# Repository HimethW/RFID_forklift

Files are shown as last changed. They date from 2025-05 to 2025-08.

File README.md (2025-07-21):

# 🚜 Forklift-Mounted RFID Reader System

A robust, industrial-grade RFID-based asset tracking system designed for real-time inventory management in warehouse environments. This project integrates embedded hardware and full-stack web technologies to automate and optimize warehouse logistics using a forklift-mounted RFID reader.

---

## 📌 Project Overview

This system enables forklifts to detect RFID-tagged goods during pallet movement and automatically update inventory data via Wi-Fi to a centralized web dashboard. It improves warehouse efficiency by minimizing manual data entry and ensuring accurate, real-time inventory tracking.

---

## 🔧 Key Features

- 📡 **RFID Tag Detection**: High-frequency (13.56 MHz) RFID tag scanning using PN532.
- 🧠 **Embedded Controller**: ATmega328P-based control for RFID and communication tasks.
- 🌐 **Wi-Fi Integration**: ESP8266 transmits data wirelessly to backend server.
- 🖥️ **Web Dashboard**: Real-time inventory tracking and management via React frontend and Express + PostgreSQL backend.
- 🔩 **Custom Enclosure & PCB**: Vibration-resistant, forklift-compatible hardware with modular design and test-point access.

---
## 🧠 System Architecture

```text
[RFID Tag]
    ↓
[PN532 Reader] ←→ [ATmega328P MCU] ←→ [ESP8266 WiFi Module] → [Web Server]
                                                       ↓
                                               [PostgreSQL Database]
                                                       ↓
                                               [React Web Dashboard]

```

## 🎬 Video Demonstration
The video demonstration for our RFID reader can be viewed from [here](https://drive.google.com/drive/folders/12UP2MRnLVZfh7hwHNPXHZd3cqawokBNq?usp=sharing)

## ⚙️ Technologies Used

### 🖥️ Hardware
- ATmega328P (QFP)
- PN532 RFID Reader
- ESP8266-12F Wi-Fi Module
- LM2596 Buck Converter
- Custom PCBs (EasyEDA)
- SolidWorks Enclosure Design

### 💻 Software
- Embedded C (SPI & UART protocols)
- React + Vite (Frontend)
- Express.js (Backend)
- PostgreSQL (Database)
- Node.js

---

## 🚀 Functional Workflow

1. RFID reader (PN532) detects and reads nearby tags.
2. ATmega328P processes the UID and sends it to ESP8266 via UART.
3. ESP8266 transmits tag data to a remote PostgreSQL database.
4. Web app updates inventory and shipment statuses in real time.

---

## 🧪 Field Testing

- Verified tag detection accuracy, Wi-Fi stability, and user workflows  
- Refined enclosure and PCB based on field challenges (vibrations, range, alignment)  

---

## 👨‍💻 Contributors

- Udugamasooriya P.H.J.  
- Perera A.L.C.K.  
- Aazir M.A.M.  
- Ranaweera R.P.D.D.H.
- De Alwis W.M.R. 
- Walgampaya H.K.B.  
- Vidmal S.S.A.A.  
- Rathnayake R.M.T.N.B.  

---

## 📃 License

This project is licensed under the [MIT License](LICENSE).  

---

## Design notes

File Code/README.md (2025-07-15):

## Microcontroller Program for Forklift-Mounted RFID Reader

The microcontroller code consists of the `main.cpp` file containing the main logic running on the device, and five important supplementary libraries, `Pins.h`, `Timer.h`, `SerialInterface.h`, `SPI.h`, and `PN532.h`.

### `Pins` Class

Abstracts away the register level manipulations required to control and communicate with the I/O pins of the ATMega328P. Each I/O pin on the ATMega328P belongs to one of three ports `B` through `D`, and assigned a number `0` through `7`, within that port.

#### Constructor
`Pin pin_name(unsigned char port, unsigned char pin)`

`port` can be any of `B`, `C`, or `D`, and `pin` is any integer from `0` to `7` (both inclusive). Initializes an object to control and communicate with the pin at that port and position.

e.g. `Pin my_pin(B, 7)` refers to pin `PB7` on the ATMega328P.

#### Methods
1. `set_output()`

    Configure the pin as an output pin.

2. `set_input()`

    Configure the pin as an input pin.

3. `assert()`

    Assert the pin, i.e., drive the pin high. Requires the pin to be configured as an output to work.

4. `deassert()`

    Deassert the pin, i.e., drive the pin low. Requires the pin to be configured as an output to work.

5. `toggle()`

    Toggle the pin from its previous state; high to low or low to high. Requires the pin to be configured as an output to work.

6. `state()`

    Read the current logic level at the pin. Requires the pin to be configured as an input to work. Returns `bool`: `true` if the pin is high and `false` otherwise.

7. `is_low()`

    Returns `bool`: `true` if the current logic level at the pin is low, and `false` otherwise. Requires the pin to be configured as an input to work.

8. `is_high()`

    Returns `bool`: `true` if the current logic level at the pin is high, and `false` otherwise. Requires the pin to be configured as an input to work.

### `Timer.h` Library

Uses `TIMER0` on the ATMega328P to generate delays.

#### Functions
1. `initialize_timer()`

    Enable `TIMER0` in the correct mode. Execute once before using any delays.

2. `blocking_delay(unsigned long duration, unsigned char unit)`

    Generate a blocking (program execution halted for the entire duration) delay of `duration` units of time, where `unit` specifies the unit of time. `unit` can be either `MILLISECONDS` or `MICROSECONDS`.

    e.g. `blocking_delay(1000, MILLISECONDS)` generates a blocking delay of 1000 milliseconds or 1 second.

### `SerialInterface` Class

Provides an interface to transmit and receive bytes over the hardware serial port on the ATMega328P. We assume that the CPU clock is 16 MHz.

#### Constructor
`SerialInterface serial_interface_name(unsigned long baud_rate)`

Initializes the hardware serial port to both transmit and receive over the specified `baud_rate`.

#### Methods
1. `send(unsigned char* send_bytes, int num_bytes)`

    Accepts a pointer `send_bytes` to an array of length `num_bytes`, and transmits each byte in the array over the hardware serial transmitter, one after the other, starting with `send_bytes[0]` and ending with `send_bytes[num_bytes - 1]`. Returns `bool`: `true` when all bytes are successfully transmitted.

2. `receive(unsigned char* receive_buffer, int num_bytes)`

    Accepts a pointer `receive_buffer` to an array of length `num_bytes`, and buffers the next `num_bytes` bytes read through the hardware serial receiver into it. The first byte read goes in `receive_buffer[0]` and the last one in `receive_buffer[num_bytes - 1]`. Returns `bool`: `true` when all bytes are successfully received.

### `SPI_Master` Class

Initializes the ATMega328P as an SPI Master and handles data transmission and reception.

#### Constructor
`SPI_Master spi_master_name()`

Define an `SPI_Master` object to access the hardware SPI port on the ATMega328P.

#### Methods
1. `initialize(unsigned char data_order)`

    Initialize the hardware SPI port to send and transmit in the specified `data_order`. `data_order` can be `MSB_FIRST` or `LSB_FIRST`.

2. `send_and_receive_byte(unsigned char send_byte, unsigned char* receive_byte)`

    Send the byte `send_byte` to the slave, and read the byte simultaneously transmitted by the slave into `receive_byte`. Returns `bool`: `true` when the operation is successfully completed.

3. `send(unsigned char* send_bytes, int num_bytes)`

    Accepts a pointer `send_bytes` to an array of length `num_bytes`, and transmits each byte in it over the MOSI pin. Returns `bool`: `true` once all bytes in the array are successfully transmitted.

4. `receive(unsigned char* receive_buffer, int num_bytes)`

    Accepts a pointer `receive_buffer` to an array of length `num_bytes`, and buffers `num_bytes` bytes in it over the MISO pin. Returns `bool`: `true` once `num_bytes` bytes are successfully received.

### `PN532` Class

Provides an interface to communicate with NXP's PN532 RFID chip.

#### Constructor
`PN532 my_pn532(Pin NSS)`

Define a `PN532` object to control the PN532, selected over the `NSS` `Pin`, i.e., `Pin` `NSS` on the ATMega328P must be connected to pin NSS on the PN532.

#### Methods
1. `initialize()`

    Initialize the hardware SPI port for communication with the PN532 and keep it deselected to begin with.

2. `send_bytes(unsigned char* bytes, int length)`

    Send the bytes in the array of length `length` pointed to by `bytes` to the PN532. Returns `bool`: `true` once all bytes are sent.

3. `receive_bytes(unsigned char* buffer, int length)`

    Buffer `length` bytes from the PN532 into the array pointed to by `buffer`. Returns `bool`: `true` when `length` bytes are received.

4. `write_frame(unsigned char* frame, int length)`

    Accept a pointer to an array `frame`, whose entries are the various bytes in a normal information frame, modify it as necessary, and send it to the PN532 over SPI (as defined in the PN532 User Manual).

5. `read_frame(unsigned char* frame_target, int length, bool start = false, bool conclude = false)`

    Buffer `length` bytes of a frame from the PN532 into the array pointed to by `frame_target`. `start` and `conclude` allow to read a frame portion by portion.
    
    If `start` is `true`, an initialization procedure to start reading a frame from the PN532 is performed. If `false`, it is assumed that the initialization was previously performed, and will not be performed; use if a `read_frame` was previously issued, but all bytes of the frame being sent were not read then.
    
    If `conclude` is `true`, a conclusion procedure to conclude reading the frame from the PN532 is performed. Set to `false` if not all of the bytes in the response frame are being buffered, and it is intended to buffer the remaining bytes in the response with future calls to `read_frame`.

    Returns `bool`: `true` if `length` bytes are read.

    e.g. Say the PN532 has a frame of length 20 ready to be read. Three calls to `read_frame` can be made as follows.
    
    `read_frame(buffer_1, 10, true, false)` performs the initialization procedure, and reads the first 10 bytes in the frame into `buffer_1`.
    
    `read_frame(buffer_2, 5, false, false)` reads the next 5 bytes of the frame response into `buffer_2`. The initialization procedure will not be performed.
    
    `read_frame(buffer_3, 5, false, true)` reads the last 5 bytes of the frame into `buffer_3` and performs the conclusion procedure, indicating we have completed reading the frame.

6. `make_normal_information_frame(unsigned char* target_frame, unsigned char TFI, unsigned char* bytes, unsigned char num_bytes)`

    Accept a pointer `bytes` to an array of length `num_bytes` containing the data bytes (`PD0` to `PDn` as per PN532's User Manual) to be included in a normal information frame, the relevant TFI, construct the frame with the frame header and trailer and place it in the array pointed to by `target_frame`.

    `TFI` can be either `TFI_PN532_TO_HOST` or `TFI_HOST_TO_PN532` and indicates the direction of data transfer.

    Two constants `FRAME_HEADER_SIZE` and `FRAME_TRAILER_SIZE` are defined in the library. It is required that `target_frame` have length `FRAME_HEADER_SIZE + num_bytes + FRAME_TRAILER_SIZE`.

7. `ready_to_respond()`

    Returns `bool`. Poll the PN532 for one second see if it has a frame ready to be read in that time. Returns `true` if a frame is detected, and `false` if a timeout occurs before.

8. `check_ack()`

    Returns `bool`. Read a frame from the PN532 and check if it is an `ACK` frame. Returns `true` if it is, and `false` if anything goes wrong.

9. `issue_command(PN532_Command opcode, PN532_Params... params)`

    Construct a normal information frame containing an instruction to the PN532 and send it over SPI. `opcode` must be an `unsigned char`, and possible values are in `PN532_Commands.h`. Follow `opcode` with a comma-separated list of all parameters/arguments required by it. Returns `bool`: `true` if the frame is successfully sent and acknowledged by the PN532.

10. `issue_command_from_array(unsigned char* command_array, int length)`

    Accept an array pointed to by `command_array` of length `length`, whose first entry is the command code (possible values in `PN532_Commands.h`) and following entries are arguments required by the command, and send it to the PN532 over SPI. Returns `bool`: `true` if the frame is successfully sent and acknowledged by the PN532.

11. `receive_command_response(unsigned char* response_buffer, int length, bool start = false, bool conclude = false)`

    See if the PN532 is ready to respond to a command previously issued, and buffer `length` bytes of the response frame into the array pointed to be `response_buffer`. `start` and `conclude` play the same roles as described in `read_frame`. Note that the frame header and trailer will not be stripped, and will also be placed in `response_buffer`; so it must at least have length `FRAME_HEADER_SIZE + 1 + FRAME_TRAILER_SIZE`. Returns `bool`: `true` once `length` bytes of the response are successfully read.

12. `SAMConfig()`

    Configure the PN532 to not use a SAM card. Returns `bool`: `true` if the command executed successfully.

13. `detect_card(unsigned char* card_number, unsigned char* card_data)`

    Scan the field for an ISO-14443 Type A compliant PICC, and if detected, place the logical number assigned to the card by the PN532 in `card_number`, and other details in the array pointed to by `card_data`.
    
    The length of `card_data` will depend on the number of UID bytes of the card and whether or not it is ISO-14443-4 compliant.

    In any case, the first four entries will always be respectively the MSB and LSB of the ATQA response, SAK, and the length of the UID in the number of bytes. The indices of these entries within this array will be `ATQA_MSB_IDX`, `ATQA_LSB_IDX`, `SAK_IDX`, and `UID_LEN_IDX` respectively.

    Hence, the following `card_data[UID_LEN_IDX]` bytes will contain the UID of the card. If the card is ISO-14443-4 compliant, `card[UID_LEN_IDX + card_data[UID_LEN_IDX]]` will contain the length of the `ATS` response, and the following `card[UID_LEN_IDX + card_data[UID_LEN_IDX]]` entries will contain its `ATS` response.

    Returns `bool`: `true` if a card is detected.

14. `get_mifare_classic_card()`

    Scan the field for MIFARE Classic Cards. Returns a pointer to an object of the `MIFARE_Classic_PN532` class if a card is found, containing its `UID`, and a null pointer otherwise.

### `MIFARE_Classic_PN532` Class

Abstracts away a MIFARE Classic Card detected by the PN532 and provides an interface to issue MIFARE Classic commands to the card over the PN532.

#### Constructor
`MIFARE_Classic_PN532 card_name(PN532* pn532_pcd, unsigned char* uid, int uid_length)`

`pn532_pcd` is a pointer to the `PN532` that detected and activated the card (the initiator), and `uid` is a pointer to an array of length `uid_length` `unsigned char`s that holds the UID of the card.

#### Methods
1. `issue_command(MIFARE_Classic_Command mifare_command, MIFARE_Classic_Block block_address, MIFARE_Classic_Data... data)`

    Similar to `PN532.issue_command`; accept and send a MIFARE Classic command to the card, consisting of the command code, an `unsigned char` that goes in `mifare_command` (possible values found in `MIFARE_Classic_Commands.h`), the address of the relevant block in `block_address`, and a comma-separated list of any required parameters/data (all of which must be `unsigned char`s). Returns `bool`: `true` if the command is successfully issued over the PN532.

2. `issue_command_from_array(unsigned char* command_array, int length)`

    Similar to `PN532.issue_command_from_array`. Accept a pointer `command_array` to an array of length `length`, where the first entry is the relevant MIFARE Classic command code, second entry is the address of the relevant block, and remaining entries are any required parameters/data. Returns `bool`: `true` if the command is sucessfully issued over the PN532.

3. `executed_successfully()`

    Check if the command previously issued was executed successfully. Can use in cases where the PN532 does not pass any response received from a MIFARE Classic Card back to the host controller. Returns `bool`: `true` if execution is successful.

4. `receive_command_response(unsigned char* response_buffer, int length)`

    Buffer `length` bytes from the response received from a MIFARE Classic Card to a command previously issued into the array pointed to by `response_buffer`. As per the PN532 User Manual, a response received back from a MIFARE Classic Card will be at most 16 bytes, so `length` is at most 16, and `response_buffer` should be able to hold that many entries. Returns `bool`: `true` if `length` bytes are succesfully buffered.

5. `authenticate_block(unsigned char authentication_type, unsigned char block_address, unsigned char* key)`

    Issue the command to authenticate the block at address `block_address`, using `authentication_type`, which can be either `AUTHENTICATE_KEY_A` or `AUTHENTICATE_KEY_B`, and the authentication key passed in the array pointed to by `key`. Returns `bool`: `true` if the authentication is successful and `false` otherwise.

6. `read_block(unsigned char block_address, unsigned char* contents)`

    Read the contents at the block address specified by `block_address` of a previously authenticate card, into the array pointed to by `contents`. There will be upto 16 bytes in a block, so `contents` should be able to hold upto 16 `unsigned char`s. Returns `bool`: `true` if the block is successfully read.

7. `write_block(unsigned char block_address, unsigned char* contents)`

    Write 16 bytes from the array pointed to by `contents` into the block at the address `block_address` of a previously authenticated MIFARE Classic Card. It is required that `contents` have 16 entries. Returns `bool`: `true` if the writing is successfully completed.

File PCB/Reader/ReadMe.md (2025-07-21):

# PN532 RFID PCB Design

This repository contains the complete PCB design files for an NFC RFID system based on the PN532 chip. The design includes schematic capture, PCB layout, and component libraries.

## Repository Contents

### Design Files
- **Schematic Files**:
  - Antenna circuit
  - Reader chip (PN532) interface
  - Power supply circuitry
  - Hierarchy view (top-level schematic)
  
- **PCB Layout Files**:
  - Complete board layout
  - Layer stackup
  - Manufacturing outputs

### Library Files
- `*.SchLib`: Schematic symbol libraries
- `*.PcbLib`: PCB footprint libraries

### Project Management
- `PN532_final.PrjPcb`: Altium Designer project file (or equivalent for your EDA tool)
- `pn532_LCSC_components.xlsx`: Bill of Materials (BOM) with:
  - All components used
  - Specifications
  - Reference designators
  - Supplier information

## Design Overview

The PCB implements a complete RFID reader solution using NXP's PN532 chip. Key features include:

- Operating frequency: 13.56 MHz
- Communication interfaces: [SPI, UART]
- Power supply: [5V] → [3.3V]
- Antenna design optimized for [Forklift Applications]

## Getting Started

### Prerequisites
- [Altium]

### Opening the Project
1. Clone this repository
2. Open `PN532_final.PrjPcb` in your EDA tool
3. All schematic and layout files should load automatically

## Version History
- v1.0 - Initial release
  - Basic functionality verified
  - Initial PCB prototype tested

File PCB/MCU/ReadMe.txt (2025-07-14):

This file contains the Altium files for the Micro-controller PCB

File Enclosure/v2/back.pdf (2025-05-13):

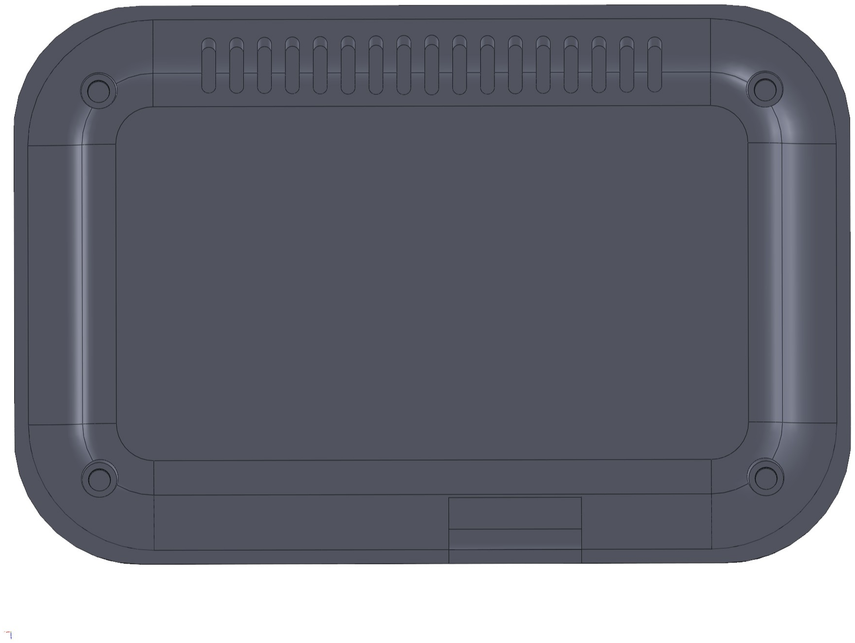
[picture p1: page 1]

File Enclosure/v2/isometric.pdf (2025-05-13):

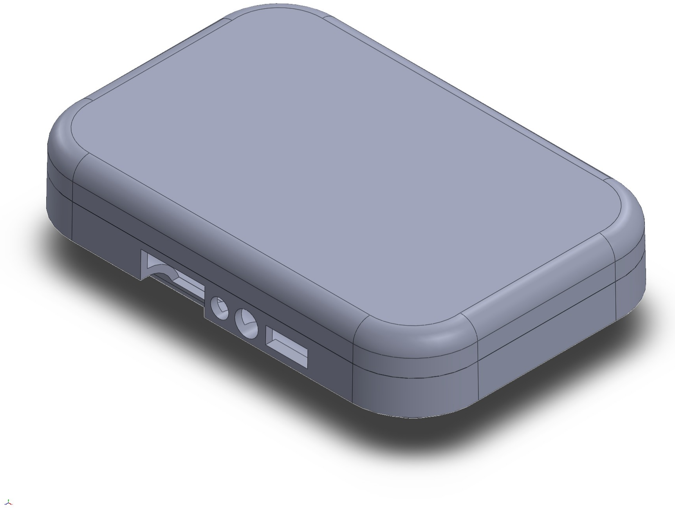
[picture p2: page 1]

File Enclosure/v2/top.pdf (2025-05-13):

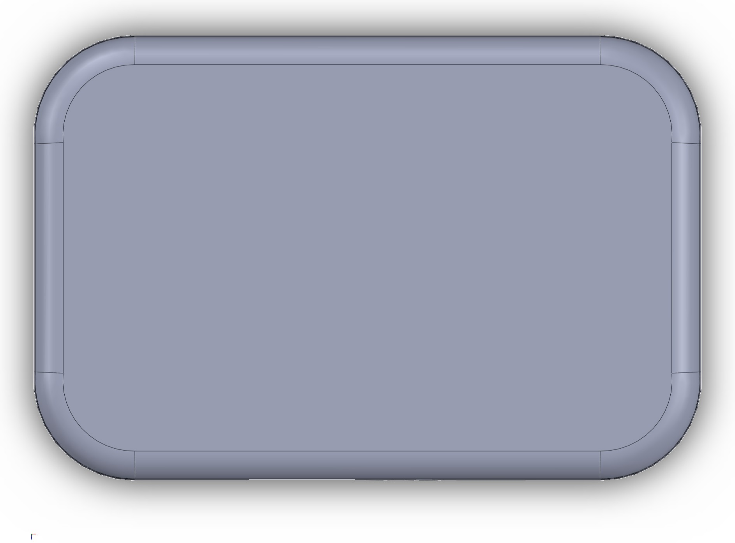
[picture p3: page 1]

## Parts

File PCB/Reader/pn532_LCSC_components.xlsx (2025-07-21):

Component | Components | Manufacture Part | LCSC Part | Manufacturer | Description | Package | Alternative
PN532 | U1 | PN5321A3HN/C106,55 | C28925 | NXP Semicon | QFN-40-EP(6x6) RFID ICs ROHS
220pF | C18,C19 | CC0805FRNPO9BN221 | C541563 | YAGEO | 50V 220pF NP0 ±1% 0805 Multilayer Ceramic Capacitors MLCC - SMD/SMT ROHS | 0805
22pF | C15,C23 | CC0805FRNPO9BN220 | C541515 | YAGEO | 50V 22pF NP0 ±1% 0805 Multilayer Ceramic Capacitors MLCC - SMD/SMT ROHS | 0805
100pF | C16,C20 | CC0805FRNPO9BN101 | C541513 | YAGEO | 50V 100pF NP0 ±1% 0805 Multilayer Ceramic Capacitors MLCC - SMD/SMT ROHS | 0805
1.5Ohm | R5,R8 | AR06FTDV1R50 | C412416 | Viking Tech | 250mW Thin Film Resistor 150V ±50ppm/℃ ±1% 1.5Ω 1206 Chip Resistor - Surface Mount ROHS | 1206
NC resistor | R6,R7 |  |  |  |  | 0402
560nH | L1,L2 | MLJ1608WR56JT000 | C502009 | TDK | 400mA 560nH ±5% 550mA 520mΩ 0603 Inductors (SMD) ROHS | 0603
0.1uF | C1,C2,C6,C7,C8,C10,C13 | CC0805JRX7R8BB104 | C520083 | YAGEO | 25V 100nF X7R ±5% 0805 Multilayer Ceramic Capacitors MLCC - SMD/SMT ROHS | 0805
10uF | C3,C9,C12,C24,C25 | C1206X106J3RACAUTO | C2171358 | KEMET | 25V 10uF X7R ±5% 1206 Multilayer Ceramic Capacitors MLCC - SMD/SMT ROHS | 1206
1kOhm | R4 | TNPW06031K00FEEA | C2131208 | Vishay Intertech | 125mW Thin Film Resistor 75V ±1% ±25ppm/℃ 1kΩ 0603 Chip Resistor - Surface Mount ROHS | 0603 | RT0603FRD071KL
1.69kOhm | R3 | RT1206BRD071K69L | C870510 | YAGEO | 250mW Thin Film Resistor ±25ppm/℃ ±0.1% 1.69kΩ 1206 Chip Resistor - Surface Mount ROHS | 1206 | RC1206FR-071K69L | alt used
1nF | C11 | CC0805FRNPO9BN102 | C326587 | YAGEO | 50V 1nF NP0 ±1% 0805 Multilayer Ceramic Capacitors MLCC - SMD/SMT ROHS | 0805
Ferrite | FB1,FB2 | BLM21AG471SN1D | C397304 | Murata Electronics | 190mΩ ±25% 470Ω@100MHz 0805 Ferrite Beads ROHS | 0805
Oscillator | Y1 | ABM8-27.120MHZ-B4-T | C7209321 | Abracon LLC | 27.12MHz 18pF ±30ppm ±50ppm SMD3225-4P Crystals ROHS | SMD3225-4P
33pF | C4,C5 | GRM1885C1H330GA01D | C426330 | Murata Electronics | 50V 33pF C0G ±2% 0603 Multilayer Ceramic Capacitors MLCC - SMD/SMT ROHS | 0603 | 06035A330FAT2A | alt used
10kOhm | R2 | ERA6VEB1002V | C490804 | PANASONIC | 250mW Thin Film Resistor 150V ±0.1% ±25ppm/℃ 10kΩ 0805 Chip Resistor - Surface Mount ROHS | 0805 | TNPW080510K0BEEA | alt used
LED-power | DS1 | LTST-C150TBKT | C125088 | Lite-On | 20mA 104mcd Colorless Transparent Lens -20℃~+80℃ 465nm~475nm Blue 130° 76mW 3.3V 1206 LED Indication - Discrete ROHS | 1206
10Ohm | R1 | RT0603DRD0710RL | C700510 | YAGEO | 100mW Thin Film Resistor 75V ±0.5% ±25ppm/℃ 10Ω 0603 Chip Resistor - Surface Mount ROHS | 0603
voltage reg | U2 | MIC5225-3.3YM5-TR | C512101 | Microchip Tech | 150mA Fixed 3.3V Positive electrode 16V SOT-23-5 Voltage Regulators - Linear, Low Drop Out (LDO) Regulators ROHS | SOT-23-5
NC capacitor | C14,C17,C21,C22

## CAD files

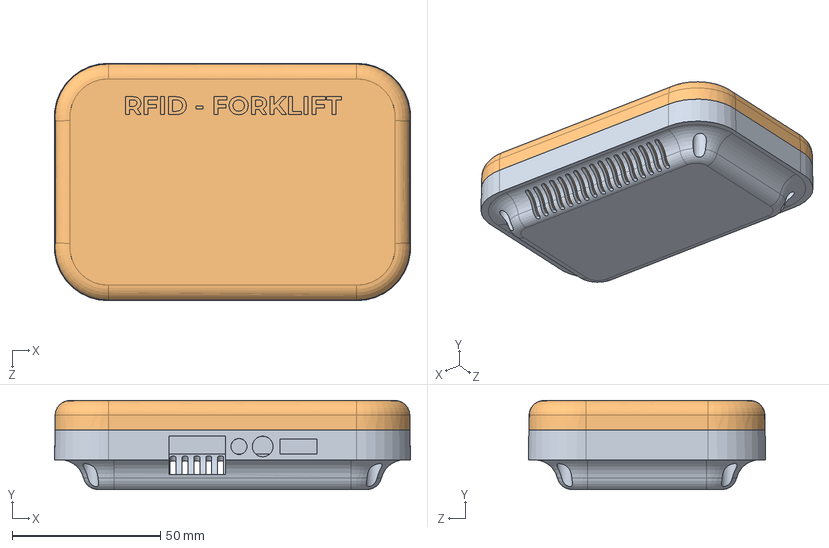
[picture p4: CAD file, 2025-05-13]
Enclosure/v2/full_enclosure.SLDASM
120.0 x 30.0 x 80.0 mm
back_cover
front_cover

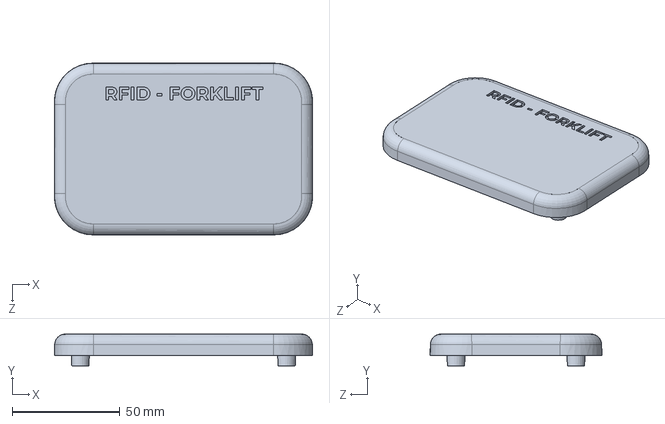
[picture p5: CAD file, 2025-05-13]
Enclosure/v2/front_cover.SLDPRT
119.7 x 14.8 x 79.7 mm

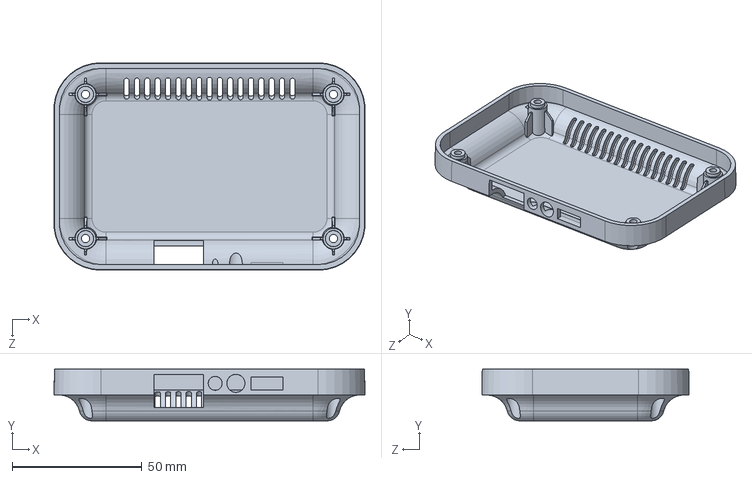
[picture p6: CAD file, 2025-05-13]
Enclosure/v2/back_cover.SLDPRT
120.0 x 20.0 x 80.0 mm

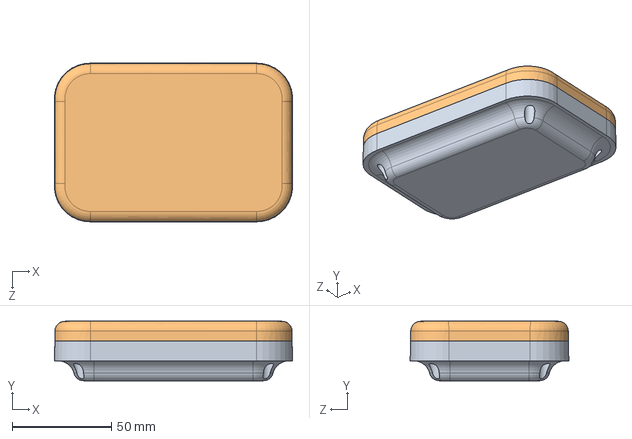
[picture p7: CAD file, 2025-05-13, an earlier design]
Enclosure/v1/Projectassm.SLDASM
120.0 x 30.0 x 80.0 mm
Projectbottom
Projecttop

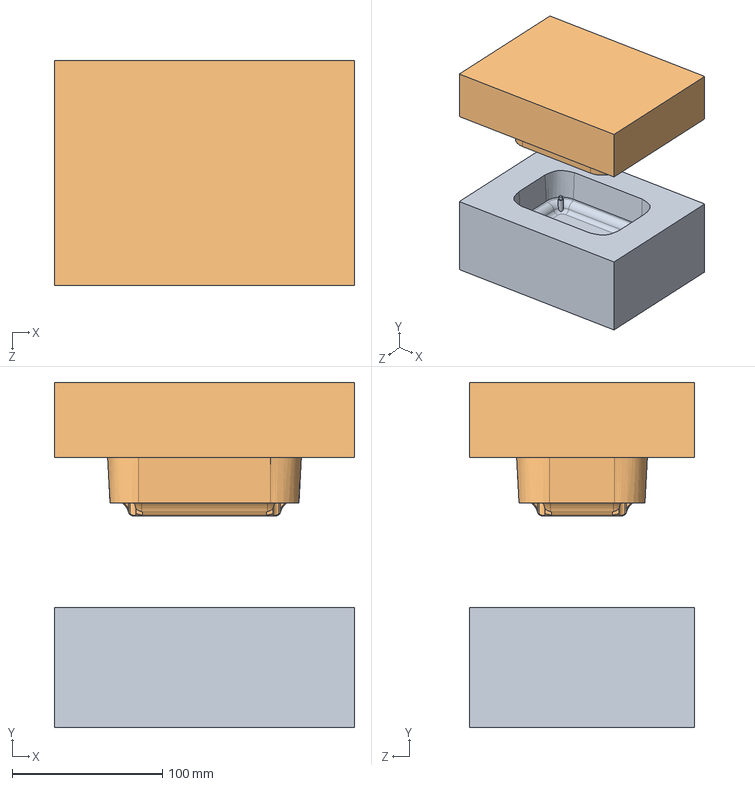
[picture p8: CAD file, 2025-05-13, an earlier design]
Enclosure/v1/Projectbottom_mold_assm.SLDASM
200.0 x 230.0 x 150.0 mm
Projectbottom_mold_cavity
Projectbottom_mold_core

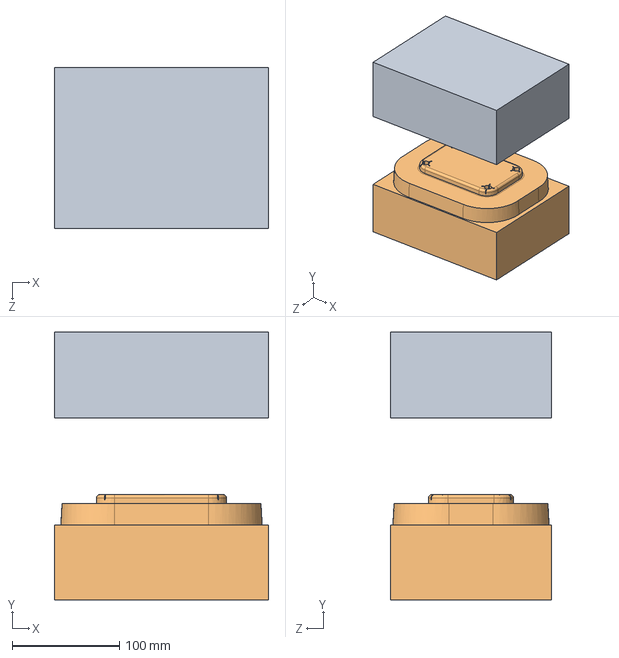
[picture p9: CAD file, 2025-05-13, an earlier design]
Enclosure/v1/Projecttop_mold_assm.SLDASM
200.0 x 250.0 x 150.0 mm
Projecttop_mold_cavity
Projecttop_mold_core

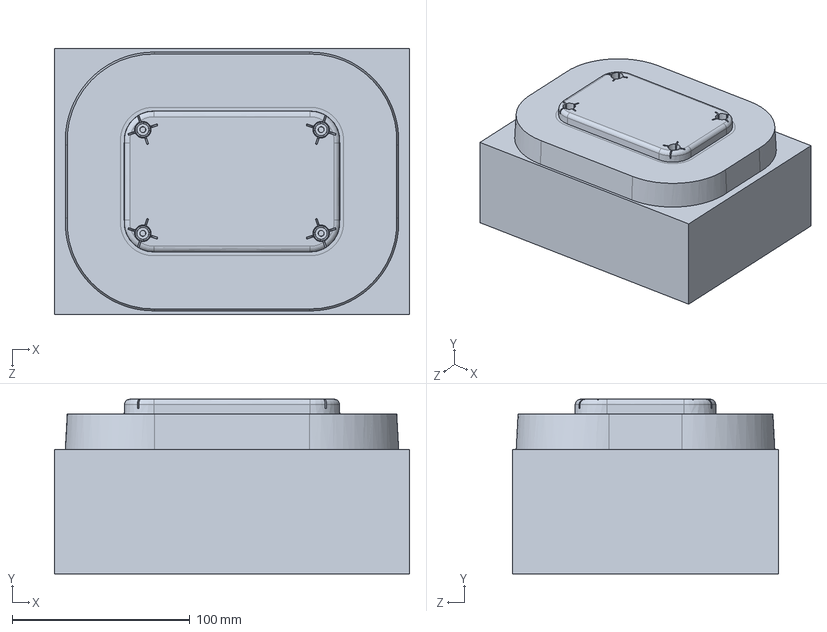
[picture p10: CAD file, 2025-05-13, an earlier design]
Enclosure/v1/Projecttop_mold_core.SLDPRT
200.0 x 98.4 x 150.0 mm

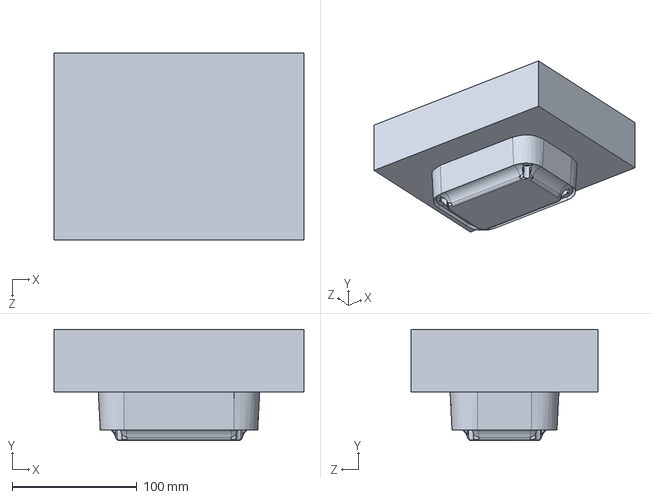
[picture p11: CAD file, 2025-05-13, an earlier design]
Enclosure/v1/Projectbottom_mold_core.SLDPRT
200.0 x 88.9 x 150.0 mm

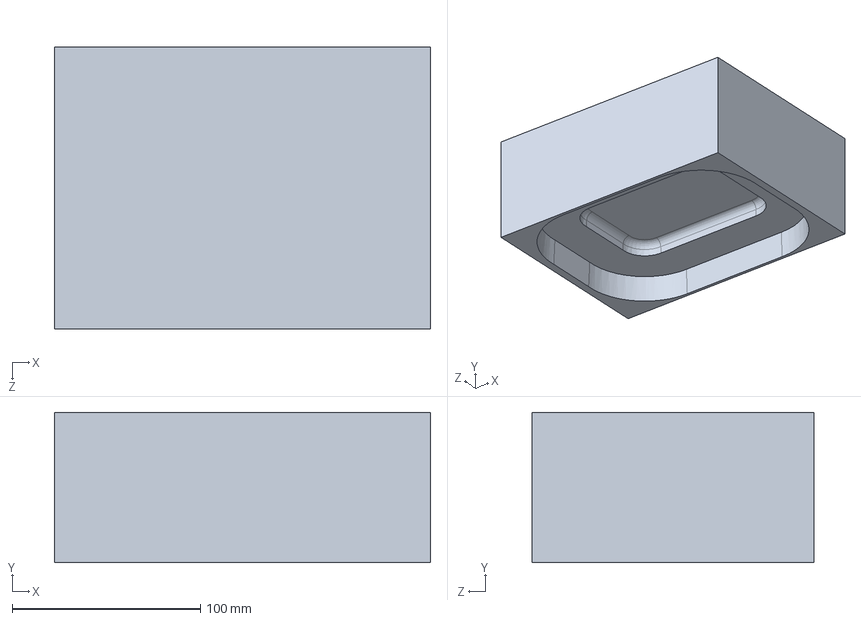
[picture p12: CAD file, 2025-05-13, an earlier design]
Enclosure/v1/Projecttop_mold_cavity.SLDPRT
200.0 x 80.0 x 150.0 mm

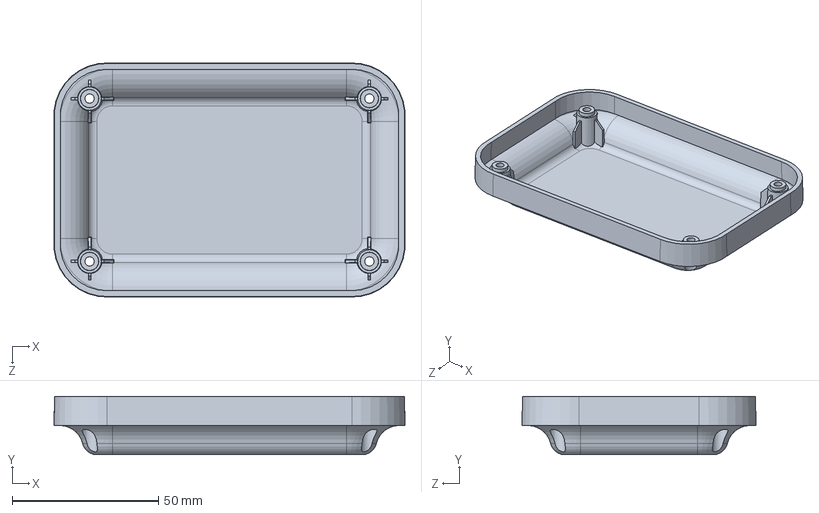
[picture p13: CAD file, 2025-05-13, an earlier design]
Enclosure/v1/Projectbottom.SLDPRT
120.0 x 20.0 x 80.0 mm

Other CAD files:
Enclosure/v1/Projectbottom_mold.SLDPRT
Enclosure/v1/Projecttop_mold.SLDPRT
Enclosure/v1/Projectbottom_mold_cavity.SLDPRT
Enclosure/v1/Projecttop.SLDPRT

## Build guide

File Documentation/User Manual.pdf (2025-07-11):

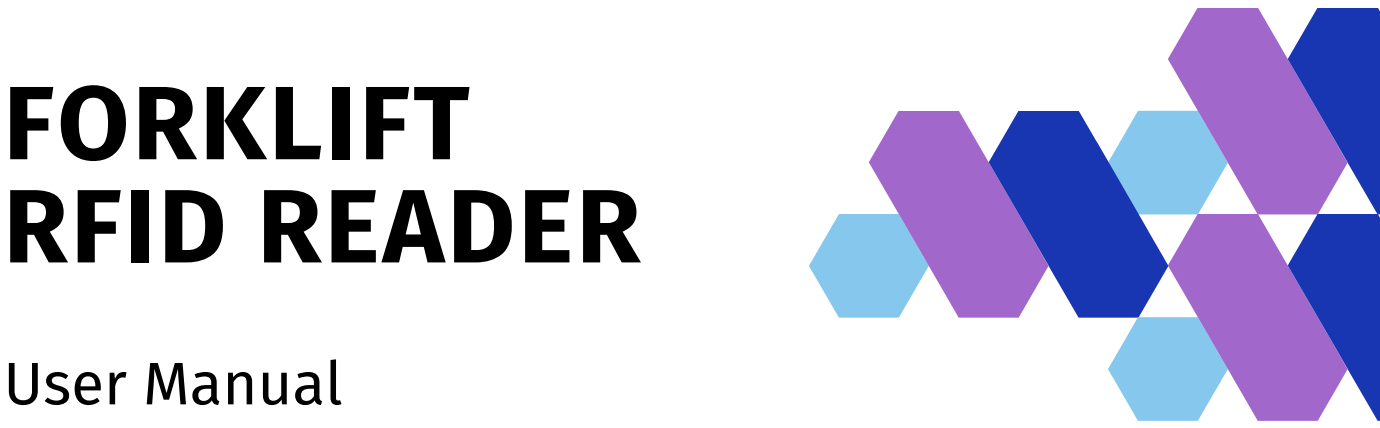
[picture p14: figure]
FORKLIFT RFID READER; User Manual
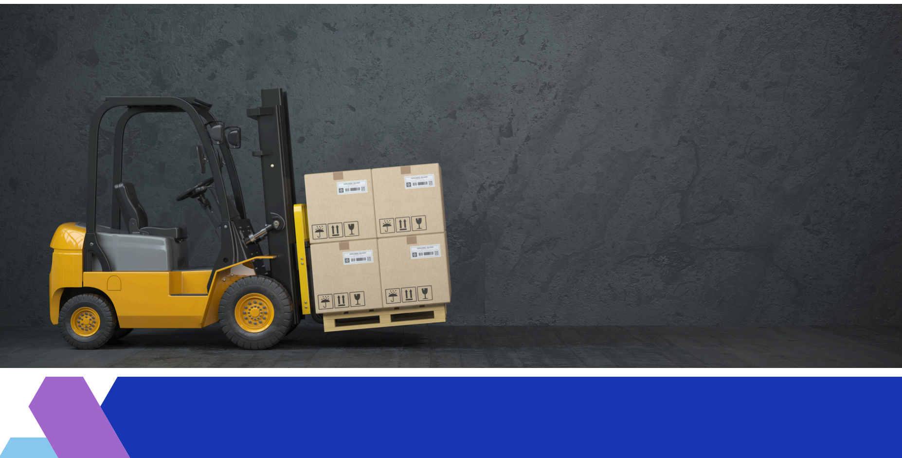
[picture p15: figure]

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
l: H

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
g Introduction Purpose of the Manual Intended Audience Overview of the RFID System Safety Information General Safety Precautions Electrical Safety Mounting Considerations Operating Instructions Powering On the System Reading RFID Tags Data Transmission User Interface Shipments Readers Warehouse Tags Users Maintenance and Troubleshooting Routine Maintenance Common Issues and Solutions

11112333344445555677788101010

## Who Should Read the Getting Started Guide

This section is intended for forklift drivers responsible for moving products within the warehouse. It provides essential information on the proper use, maintenance, and safety procedures related to the RFID reader system installed on the forklift. Understanding and following the guidelines in this manual will help ensure efficient and safe operations, as well as accurate inventory tracking.

# Getting Started Guide

## Overview and Purpose

This is a quick guide that helps forklift operators understand how to start using the RFID reader system installed on their forklifts. By following this guide, users will learn how to power on the device, read RFID tags, and transmit data effectively to the warehouse system.
By the end of this guide, you will:
Know how to start and use the RFID reader on the forklift.
Understand how to interpret tag scans.
Be aware of key maintenance and troubleshooting practices

## Quick Start Tutorial: How to Use the RFID Reader

Step 1: Powering On the System
Ensure the forklift is powered on.
Ensure the power cable is connected to the vehicle battery
The RFID reader will automatically boot up with the vehicle.
Check the indicator lights on the reader to confirm power and readiness.
Step 2: Reading RFID Tags
Drive the forklift to the newly arrived shipment
Move the forklift to a specific product where the tag is in a readable range. (The maximum readable range is 10cm)
The buzzer indicates the detection of the tag
Move the product to the destination pallet
Drive the forklift to a distance where it can detect the tag on the pallet
After detecting the pallet, you can successfully load the product on to the pallet

All the data handling tasks throughout the above process is automated. All the details regarding the interaction with the website is explained in the following sections.

## Maintenance and Troubleshooting

Regular Maintenance:
Wipe down RFID reader daily.
Check all cable connections weekly for wear or loosening.
Report any unusual noises or lights to the maintenance team.
Common Issues & Solutions:
Reader not powering on: Check forklift battery and power cable connections. No tag reads: Ensure tag is within range and not damaged. Restart reader. Data not syncing: Confirm forklift is in a network coverage area.

Always be cautious not to damage the reader while loading products onto the forklift.

This manual provides comprehensive guidance on the operation, and maintenance of the forklift-mounted RFID reader system. It is designed to assist users in effectively utilizing the RFID technology to enhance warehouse operations, ensuring accurate tracking of goods, improved inventory management, and streamlined logistics processes.

## Purpose of the Manual

# Introduction

## Intended Audience

This manual is intended for the following personnel:
Forklift Operators: Individuals responsible for the day-to-day operation of forklifts equipped with RFID readers.
System Administrators: Staff overseeing the integration of the RFID system with warehouse management systems and ensuring data integrity.
Each section of this manual is tailored to provide relevant information to these user groups, facilitating safe and efficient use of the RFID reader system.

## Overview of the RFID System

The forklift RFID reader system is an advanced solution designed to automate the identification and tracking of goods within a warehouse environment. By integrating RFID technology directly onto forklifts, the system enables real-time data capture as items are moved, loaded, or unloaded, thereby enhancing operational efficiency and accuracy.

Key components of the system include:
RFID Reader Unit: Mounted on the forklift, it emits radio signals to detect RFID tags on goods. Display on Mobile App: Provides real-time feedback to the operator, displaying information such as tag reads and system status.
Power Supply Integration: Connects to the forklift's power system, ensuring continuous operation without the need for separate charging.
Data Communication Interface: Facilitates the transfer of collected data to the warehouse management system for processing and record-keeping.
By employing this system, warehouses can achieve improved inventory accuracy, reduced manual scanning errors, and enhanced visibility into the movement of goods.

Ensuring safety during the operation and maintenance of the forklift RFID reader system is paramount. Adhere to the following precautions to prevent accidents and equipment damage: Training: Only trained and authorized personnel should operate forklifts equipped with RFID readers.
Awareness: Be mindful of the RFID reader placements to avoid collisions with warehouse structures or other equipment.
Load Handling: Exercise caution when lifting or lowering loads to prevent contact with RFID reader and to avoid damaging it during the process
Maintenance: Regularly inspect the RFID system for signs of wear or damage. Report any issues to the maintenance team promptly.

## General Safety Precautions

# Safety Information

The RFID reader system involves electrical components that require careful handling:
Power Connection: Consult with the forklift maintenance provider before connecting the RFID system to the vehicle's power supply. Use a multi-conductor cable for power connections, ensuring compatibility with the forklift's electrical system.
Battery Drain: Avoid connecting the RFID reader directly to the forklift battery without a means to control power flow. Continuous power draw can deplete the battery, potentially immobilizing the forklift. Implement a dedicated switch or integrate the system with the ignition switch to manage power effectively.
Voltage Spikes: Use a DC/DC power supply kit to filter voltage spikes that may occur during forklift startup, protecting the RFID reader's internal components.

## Electrical Safety

Proper installation of the RFID reader is crucial for safe and efficient operation: Placement: Mount the RFID reader and antennas in locations that do not obstruct the operator's view or interfere with forklift operations.
Secure Installation: Use appropriate mounting hardware to firmly attach components, preventing movement or detachment during operation.
Cable Management: Route cables through protective conduits and secure them to avoid entanglement or damage from moving parts.

## Mounting Considerations

To ensure the RFID reader system operates correctly, follow these steps to power it on:
1.Verify Power Connections: Ensure that the RFID reader is securely connected to the forklift's power supply through the multi-conductor cable integrated with the forklift's electrical system. 2.Ignition Activation: Turn the forklift's ignition key to the "ON" position. The RFID reader is designed to power on automatically with this ignition, ensuring synchronized operation. 3.System Initialization: Observe the RFID reader's status indicators:
Power LED: Should illuminate steadily, indicating that the reader is receiving power. 4.Navigate to the RFID reader App on the driver’s smartphone.

## Powering On the System

# Operating Instructions

The RFID reader is designed to automatically detect and read RFID tags within its operational range. To effectively read tags:
1.Approach the Load: Drive the forklift towards the pallet or item equipped with RFID tags. Ensure that the tags are within 10cm range from the reader.
2.Optimal Positioning: Align the forklift so that the RFID tags are directly in front of the reader. Proper alignment ensures accurate and efficient reading.
3.Reading Process: Pause briefly to allow the reader to scan the tags. The mobile App indicates the successful detection of the RFID tag as well the buzzer inside the reader.
4.Data Verification: Check the mobile App to confirm that the correct tag information has been captured.
5.Proceed with Operation: Once tag data is verified, continue with the intended task, transporting the load to its designated location.
Note: Ensure that tags are not obstructed by metal objects or other materials that may interfere with radio frequency signals.

## Reading RFID Tags

## Data Transmission

After reading RFID tags, the system transmits the collected data to the warehouse management system (WMS) for processing and record-keeping. The transmission process involves:
Wireless Communication: The RFID reader communicates with the WMS via the warehouse's wireless local area network (WLAN), ensuring real-time data transfer.
Data Formatting: Captured tag information is formatted to ensure compatibility with the WMS. Acknowledgment: The system confirms successful data transmission, which can be viewed on the mobile App status of the readers and tags (explained in the User Interface section).
Note: Ensure that the forklift remains within the coverage area of the WLAN to maintain

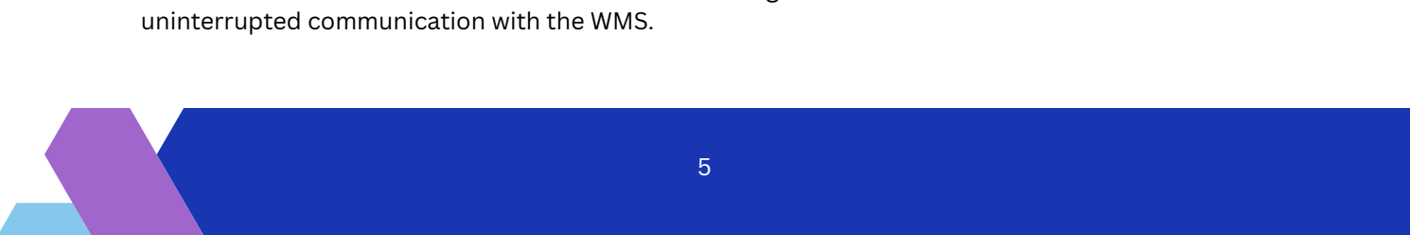
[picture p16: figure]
uninterrupted communication with the WMS.

## User Interface

Tracking of the movements of the products is entirely automated. The status of the process at a particular moment can be understood through the client application in the mobile App and the warehouse management system. The client application in the mobile App and the warehouse management system has similar display and functionality.

You have to log in to the client application by entering your username and password. The system identifies whether you are a warehouse administrator or an RFID reader user and redirects you to the appropriate web page.

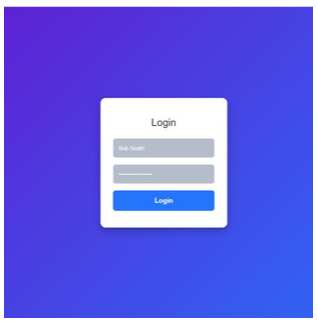
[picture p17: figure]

The web page redirected for RFID reader users is shown on the left. The user can view all the tags scanned so far with the tag name, scanned date, and time. You can also manually add RFID tags through the option at the top of the web page.

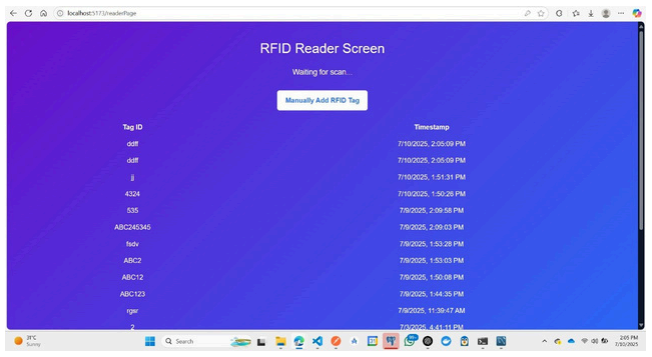
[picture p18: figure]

If you are a warehouse
administrator, you will be redirected to the webpage
shown on the right.
Initially, you will be in the Shipments tab, one of the
five main tabs: Shipments, Readers, Warehouse, Tags,
and Users.

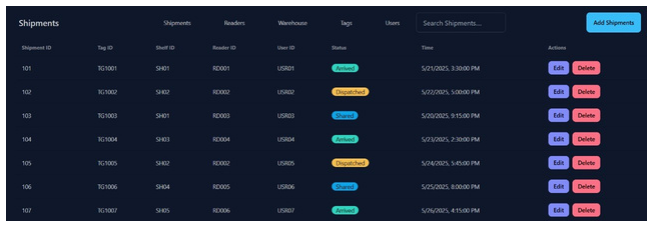
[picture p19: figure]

Shipments
This tab contains all the
information about a particular product in the warehouse. The id of the shipment which the product arrived, id of the tag assigned to it, id of the shelf if it’s successfully loaded on to the corresponding pallet in the

When a new shipment arrives at the warehouse, the management should add the tag information to the warehouse through the Add Shipments option on the top right
The status of the product at this moment is displayed as arrived. Once a forklift reads that tag it changes the status into dispatched, and the forklift moves it to the intended pallet. When the forklift reads the id of the specific pallet the tag status changes to shelved and the forklift loads it to that pallet.

warehouse, id of the reader if its currently on the move on that corresponding reader, id of the user which is the forklift if its currently on the move on it, status which can be either indicating as arrived, dispatched or shelved.

Readers
The reader can be forklift or handheld RFID which is indicated under the type. Each reader is given a specific id and a name. When a forklift reads a tag from a shipment its status is indicated as working. When it reads the id of a specific pallet before unloading the product on it, its status change into idle.

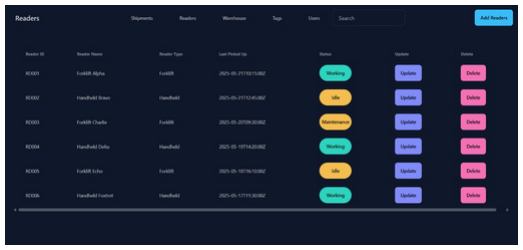
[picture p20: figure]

the warehouse management can add new readers through the Add Reader option on the top right.

Warehouse
Details of the warehouses in the complex can be found here. Each warehouse is given a specific id and a name. It also displays the information of the shelves located in it which includes the id of a particular shelf and the location of it in the warehouse.

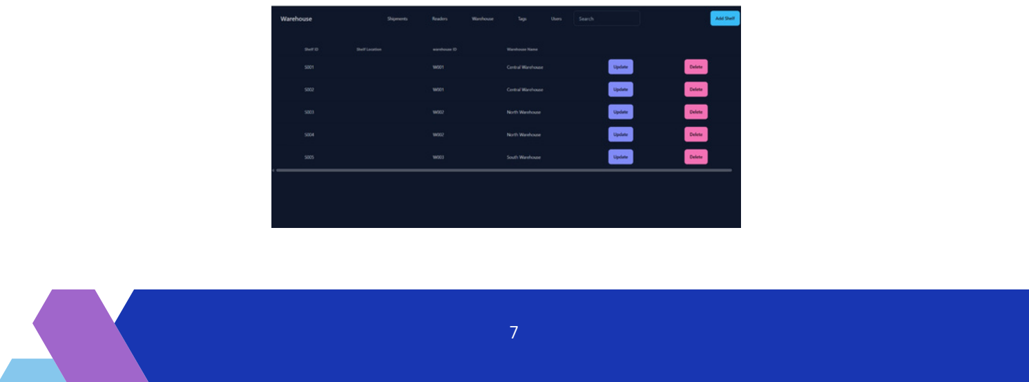
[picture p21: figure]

The warehouse management can add new warehouses through the Add Warehouse option on the top right.

Tags

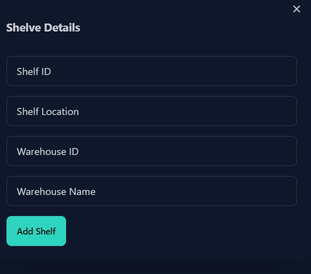
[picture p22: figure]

This tab contains all the information of the products that has been entered to the warehouse data base. It specifies the tag id along with type of the product that id.

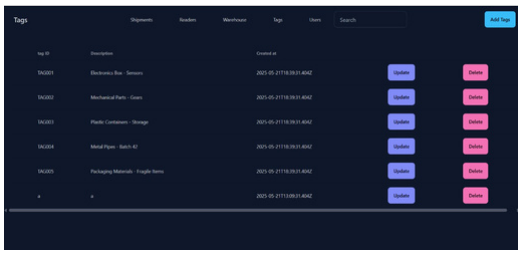
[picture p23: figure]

The warehouse management can add new tags through the Add Tag option on the top right.

Users
Details of the users of the RFID readers are included in this tab. They can be either forklifts or handheld RFIDs.

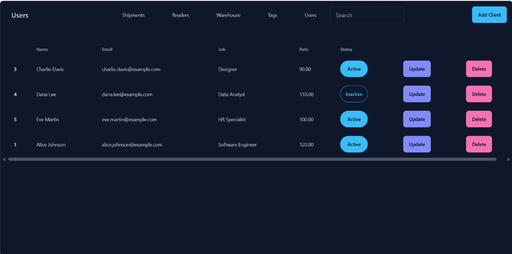
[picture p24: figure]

The warehouse management can add new users through the Add User option on the top right.

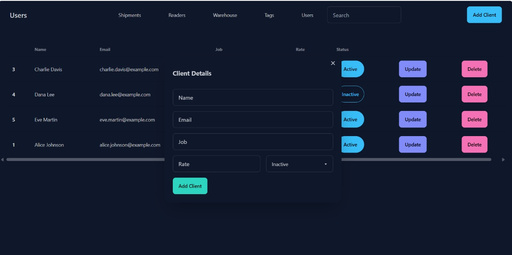
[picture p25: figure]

You can search a specific entry in each of the tabs through the search option on the top right

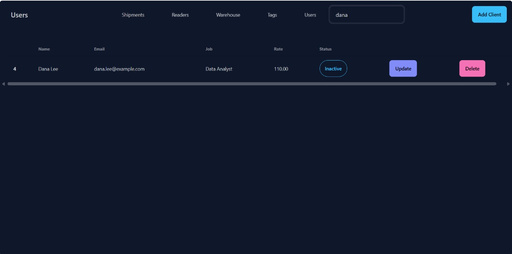
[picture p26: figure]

You can delete any entry from the data base on any tab through the delete option

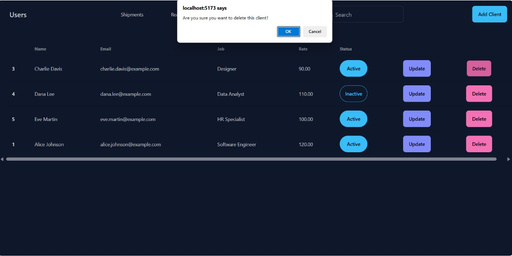
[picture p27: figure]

# Maintenance and Troubleshooting

## Routine Maintenance

Regular maintenance ensures the longevity and optimal performance of the forklift RFID system. Implement the following practices:
Visual Inspections: Periodically check RFID readers, antennas, and cables for signs of wear, damage, or loose connections.
Cleaning: Gently clean RFID components using anti-static materials to remove dust and debris that may interfere with operation.
Software Updates: Regularly update the firmware and software of RFID devices to ensure compatibility and incorporate performance enhancements.
Environmental Monitoring: Ensure that RFID components are operating within the suitable environmental conditions, avoiding exposure to extreme temperatures, moisture, or corrosive substances.
Cable Management: Secure and organize cables to prevent entanglement or damage from moving parts. Utilize cable trays or conduits where appropriate.
Issue | Possible Cause | Recommended Solution
Reader not powering on | Loose or disconnected power cable | Verify and secure all power connections
Reader not powering on | Faulty power supply | Test and replace the power supply if necessary
Inconsistent tag reads | Antenna misalignment | Adjust antenna positioning for optimal tag detection

## Common Issues and Solutions

The following table outlines potential issues with the RFID system and recommended solutions:

Inconsistent tag reads | Interference from metal objects | Reposition tags or use on-metal RFID tags to mitigate interference
No data transmission to WMS | Network connectivity issues | Check network connections and configurations
System freezes or becomes unresponsive | Software glitches or memory overload | Restart the system and monitor for recurring issues; update software to the latest version
Reader does not pick up the tag | Faulty antenna | Test with a known good antenna to determine if replacement is necessary

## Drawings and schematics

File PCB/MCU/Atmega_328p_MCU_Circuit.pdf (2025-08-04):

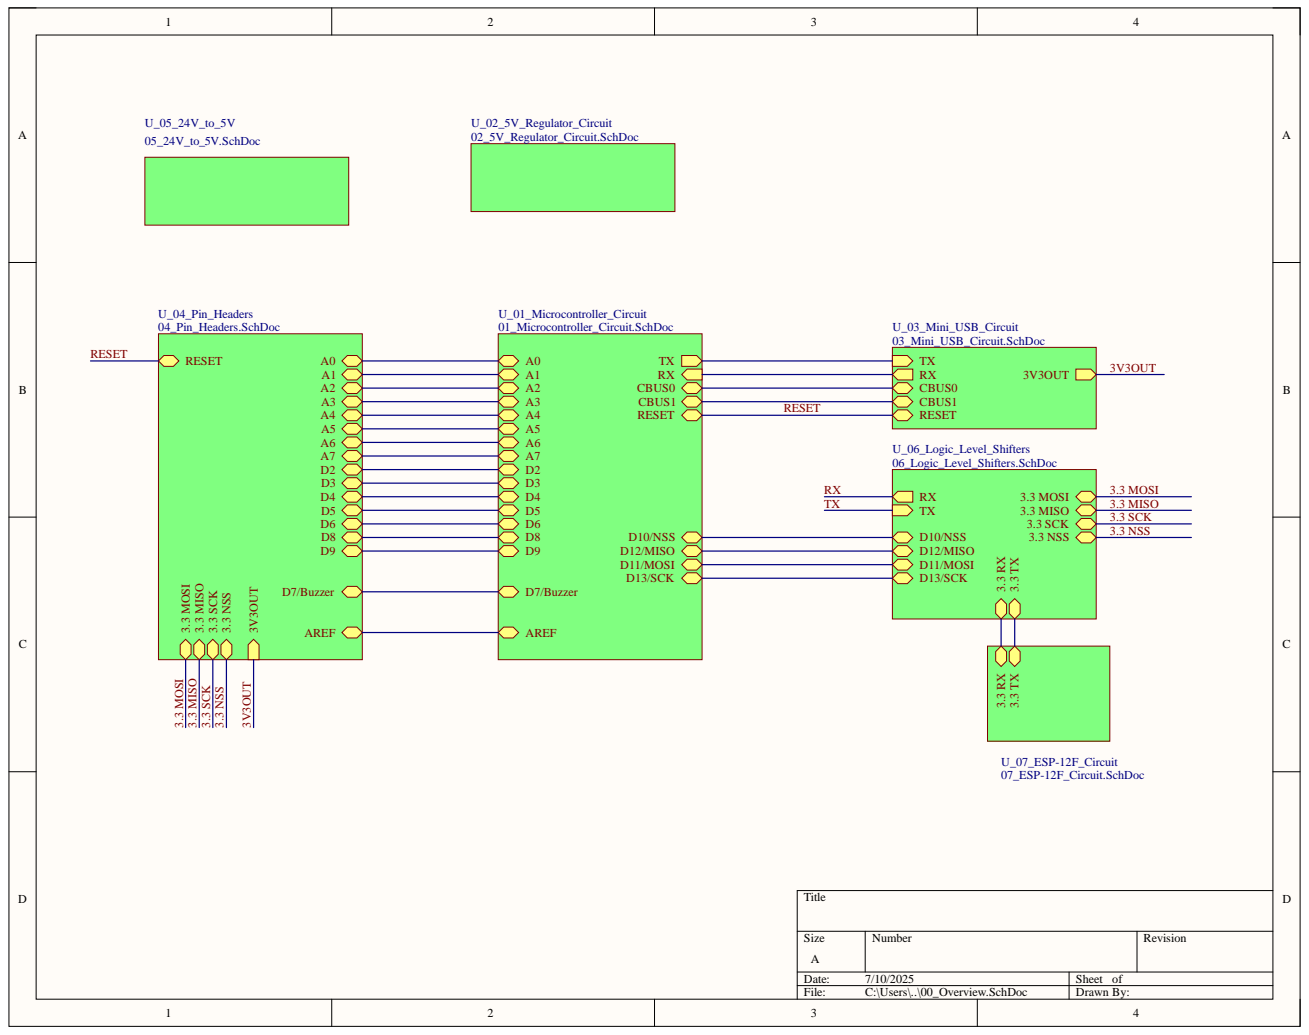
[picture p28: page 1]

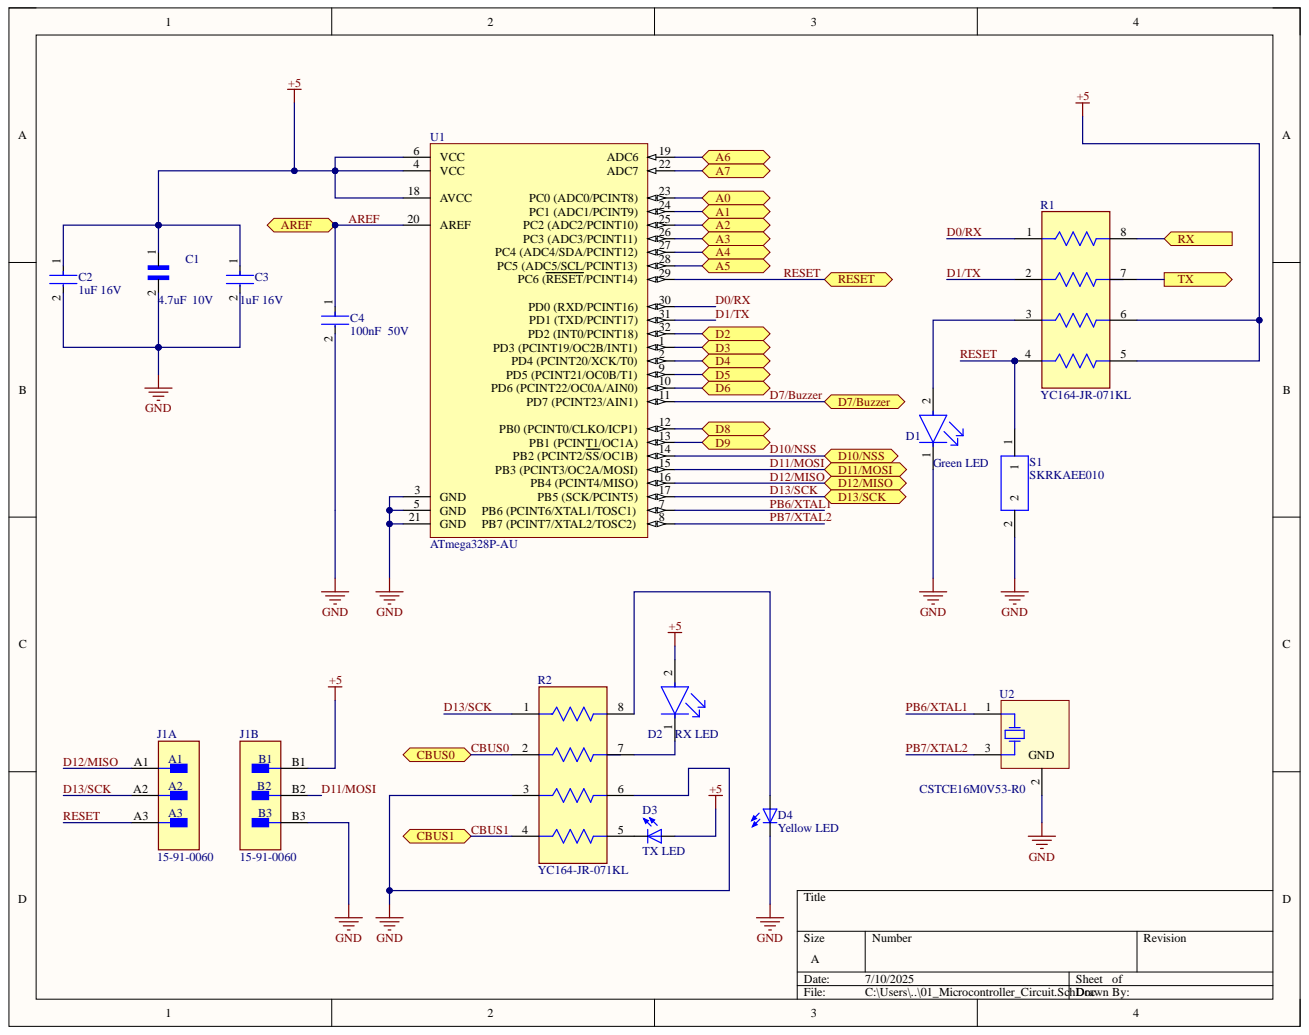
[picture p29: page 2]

AVCC 18

C1 | | GND 3

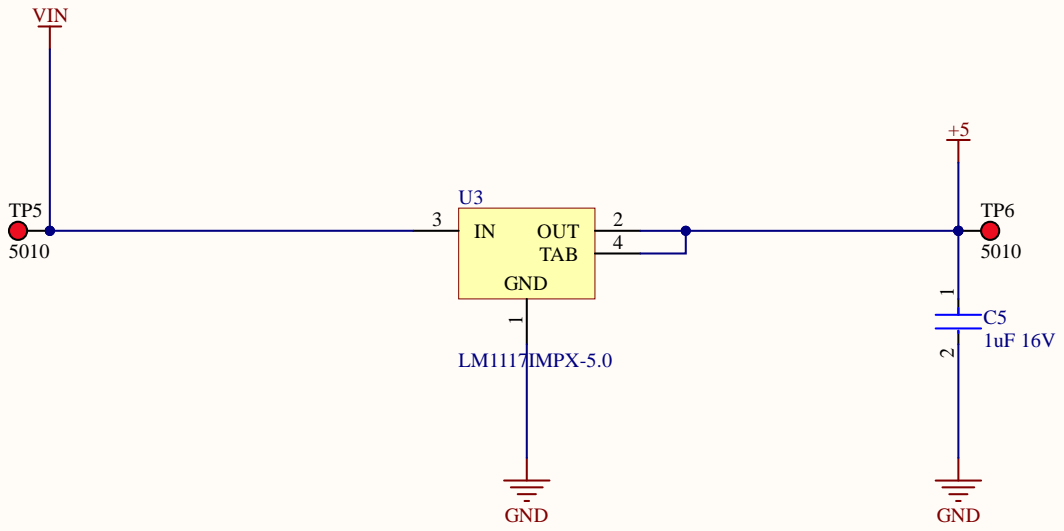
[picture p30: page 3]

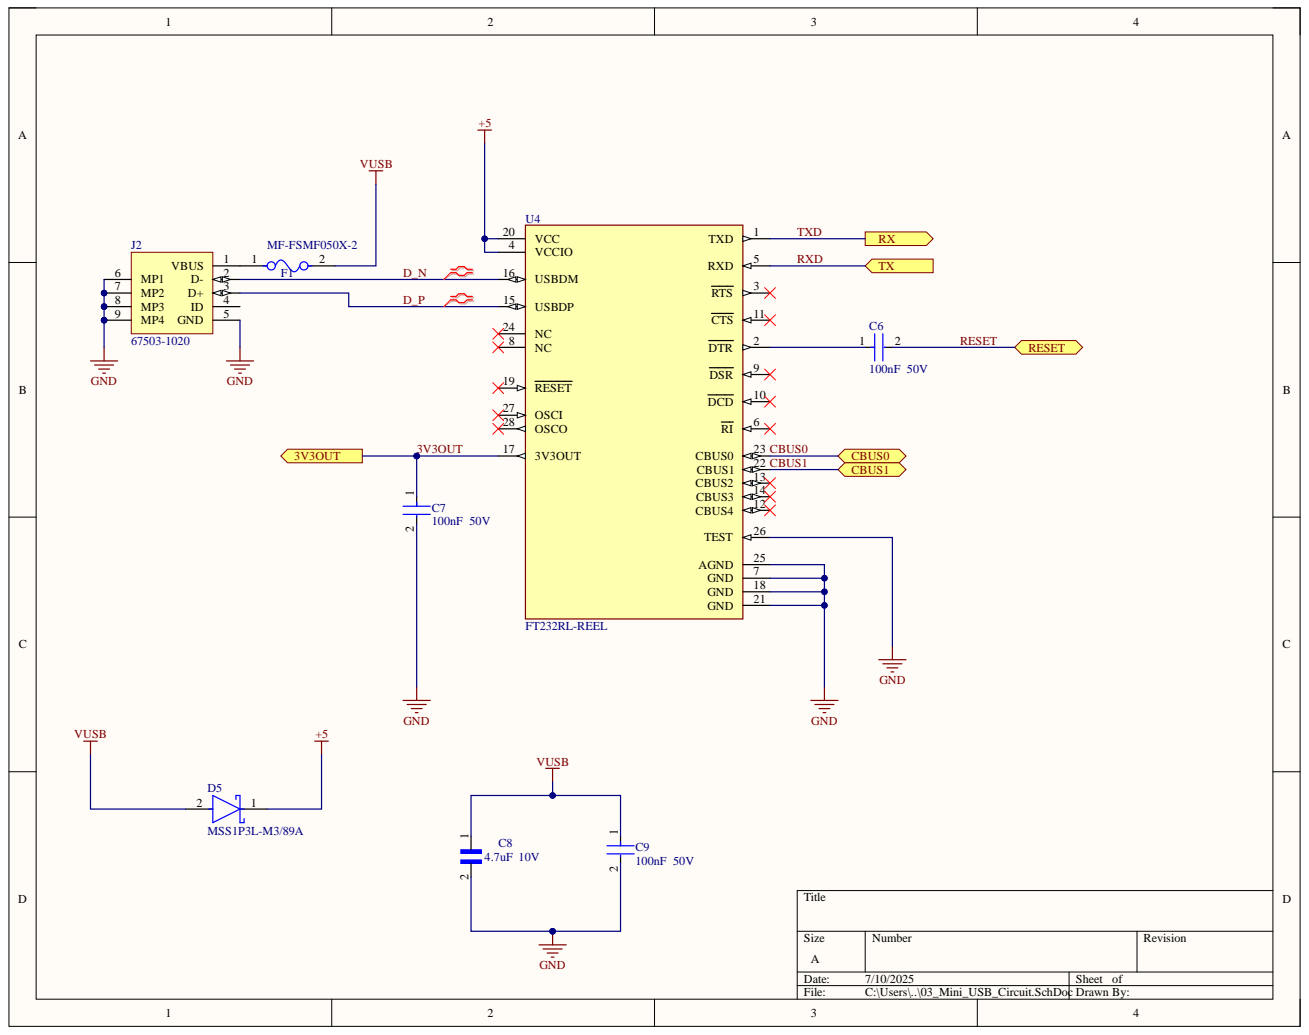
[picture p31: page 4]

MP3 8 | D_P
MP4 9 | NC 8 NC 24

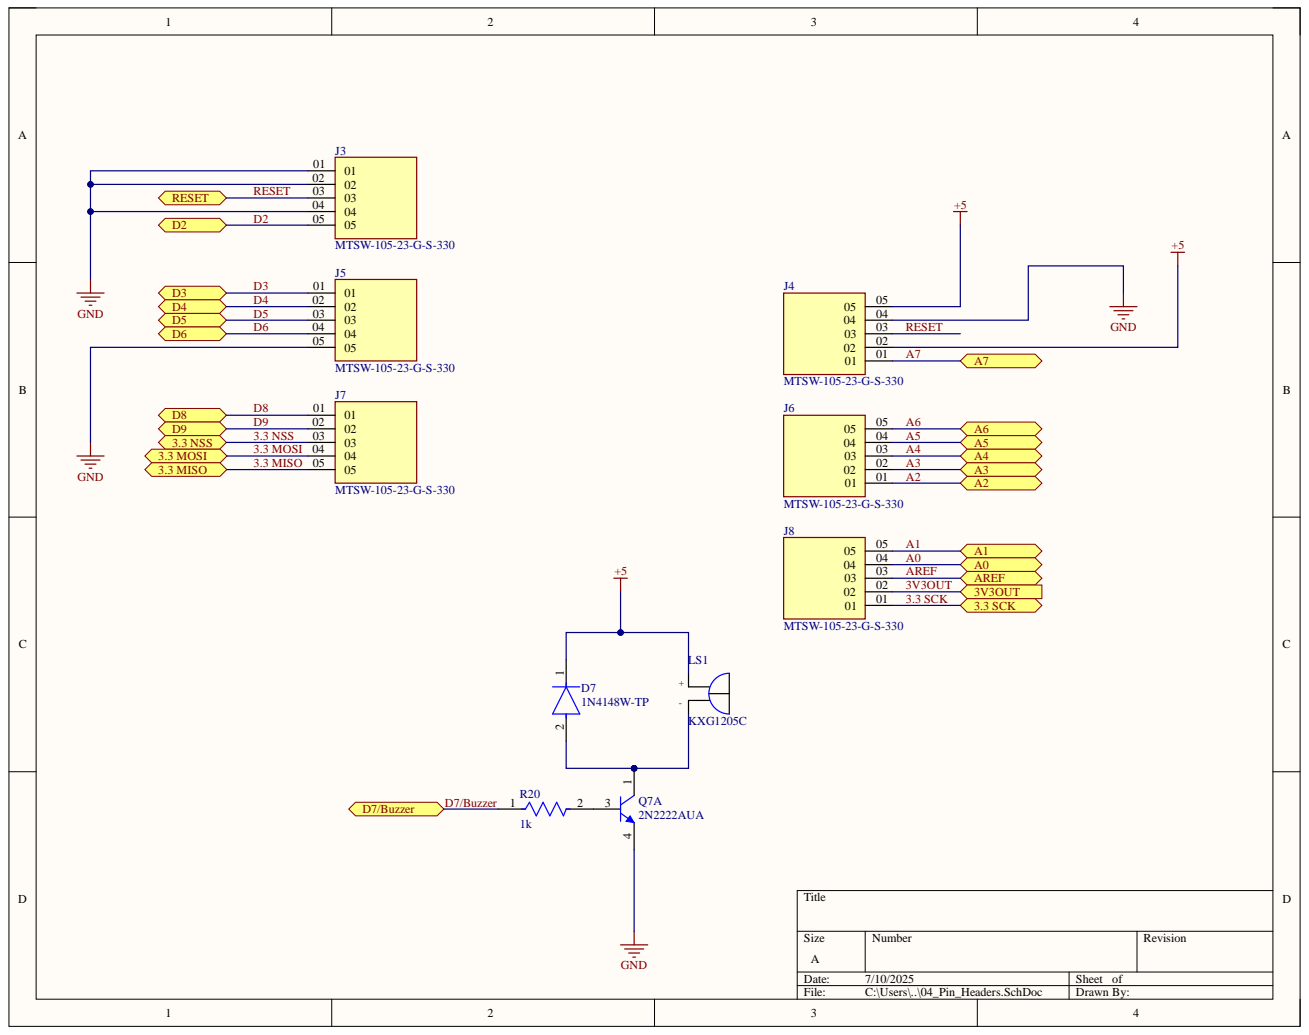
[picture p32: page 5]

RESET | 03 03 04 04

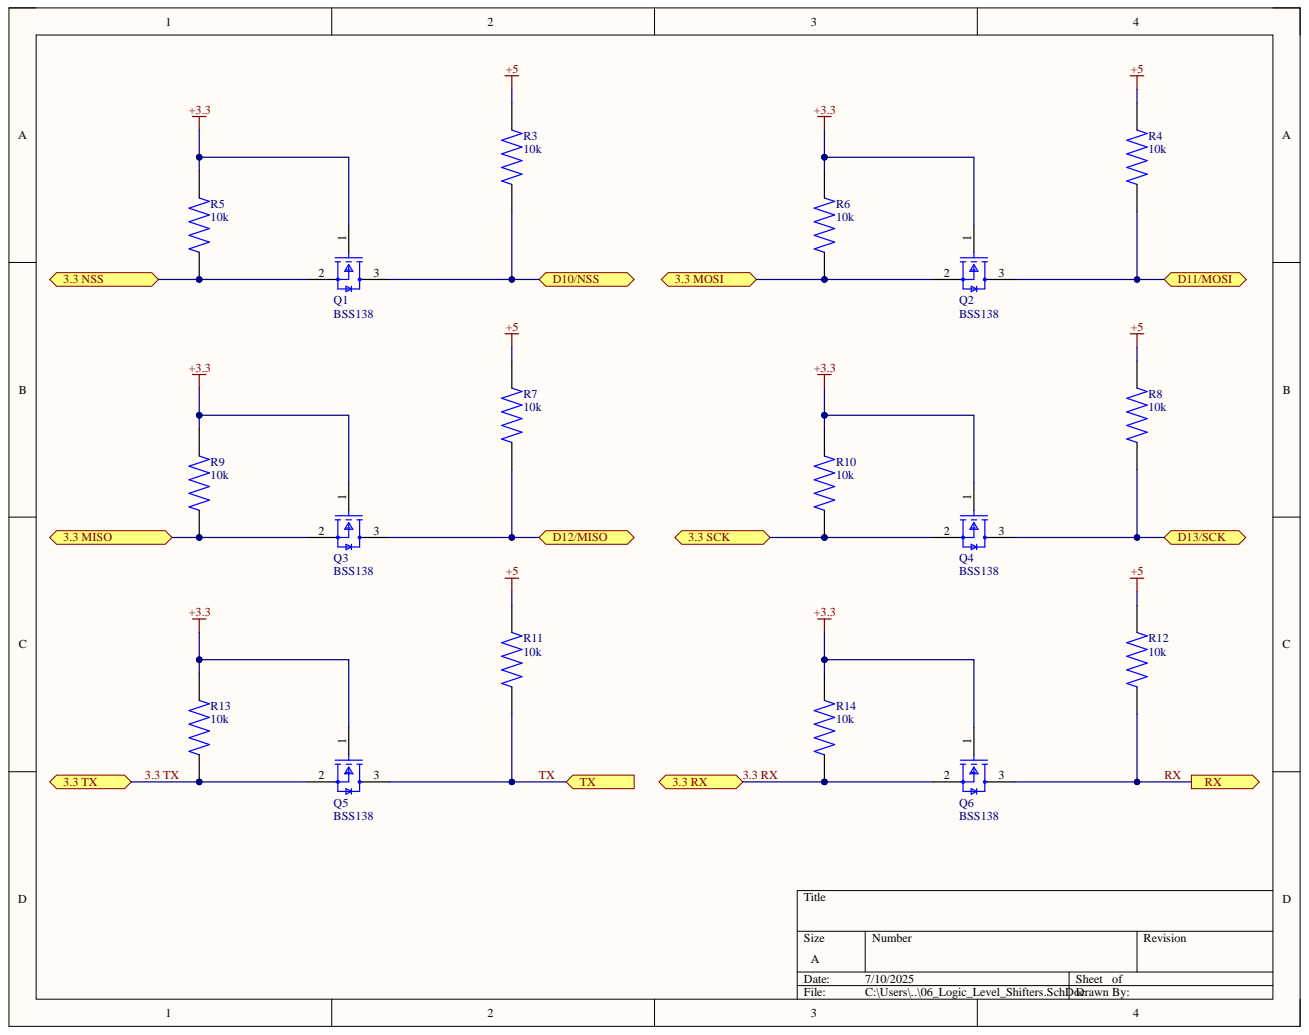
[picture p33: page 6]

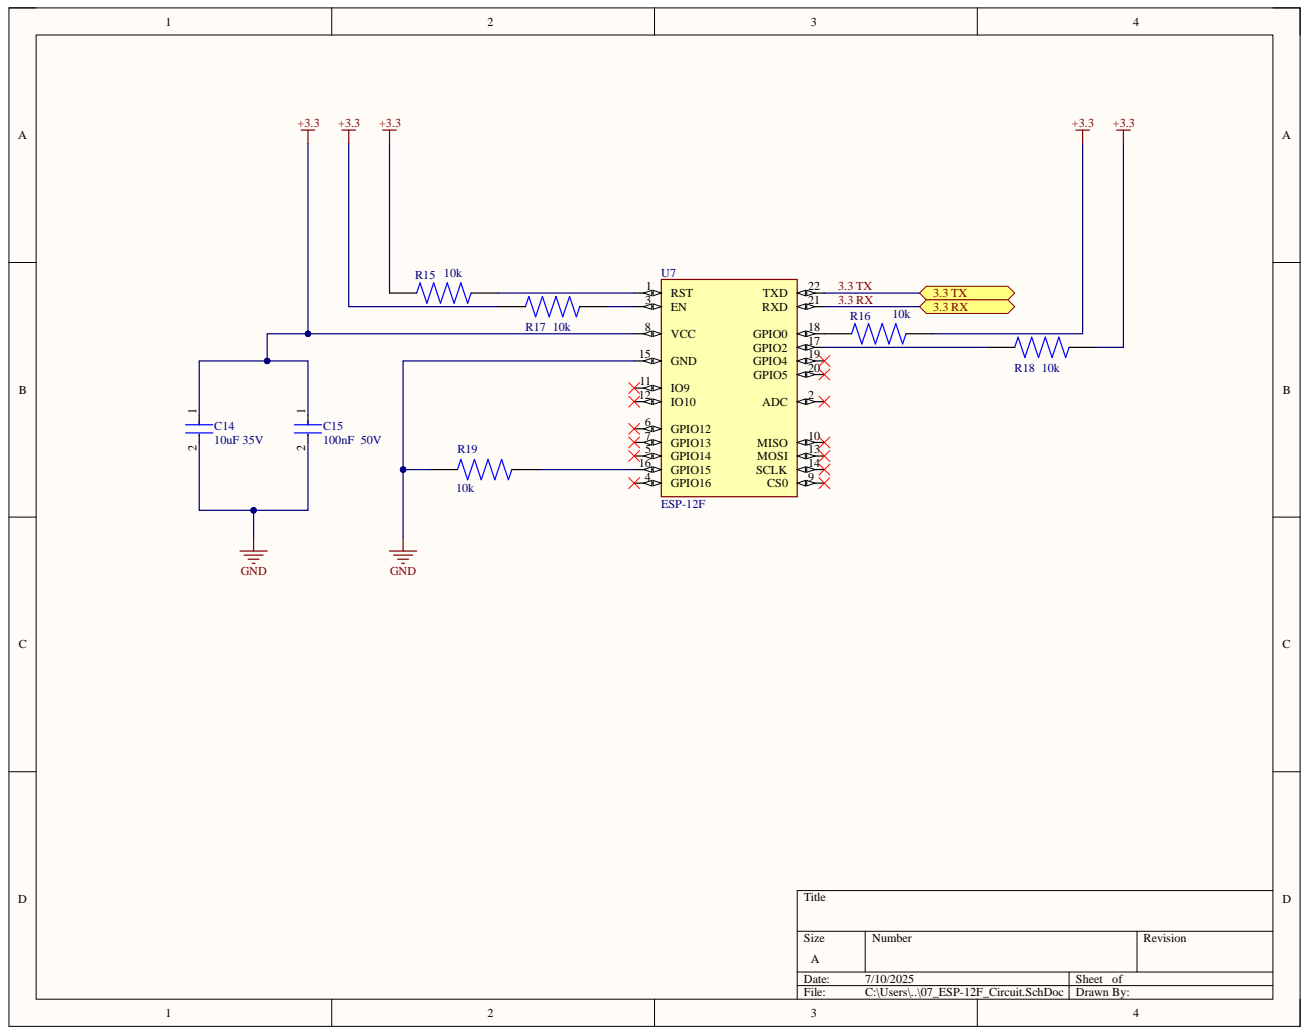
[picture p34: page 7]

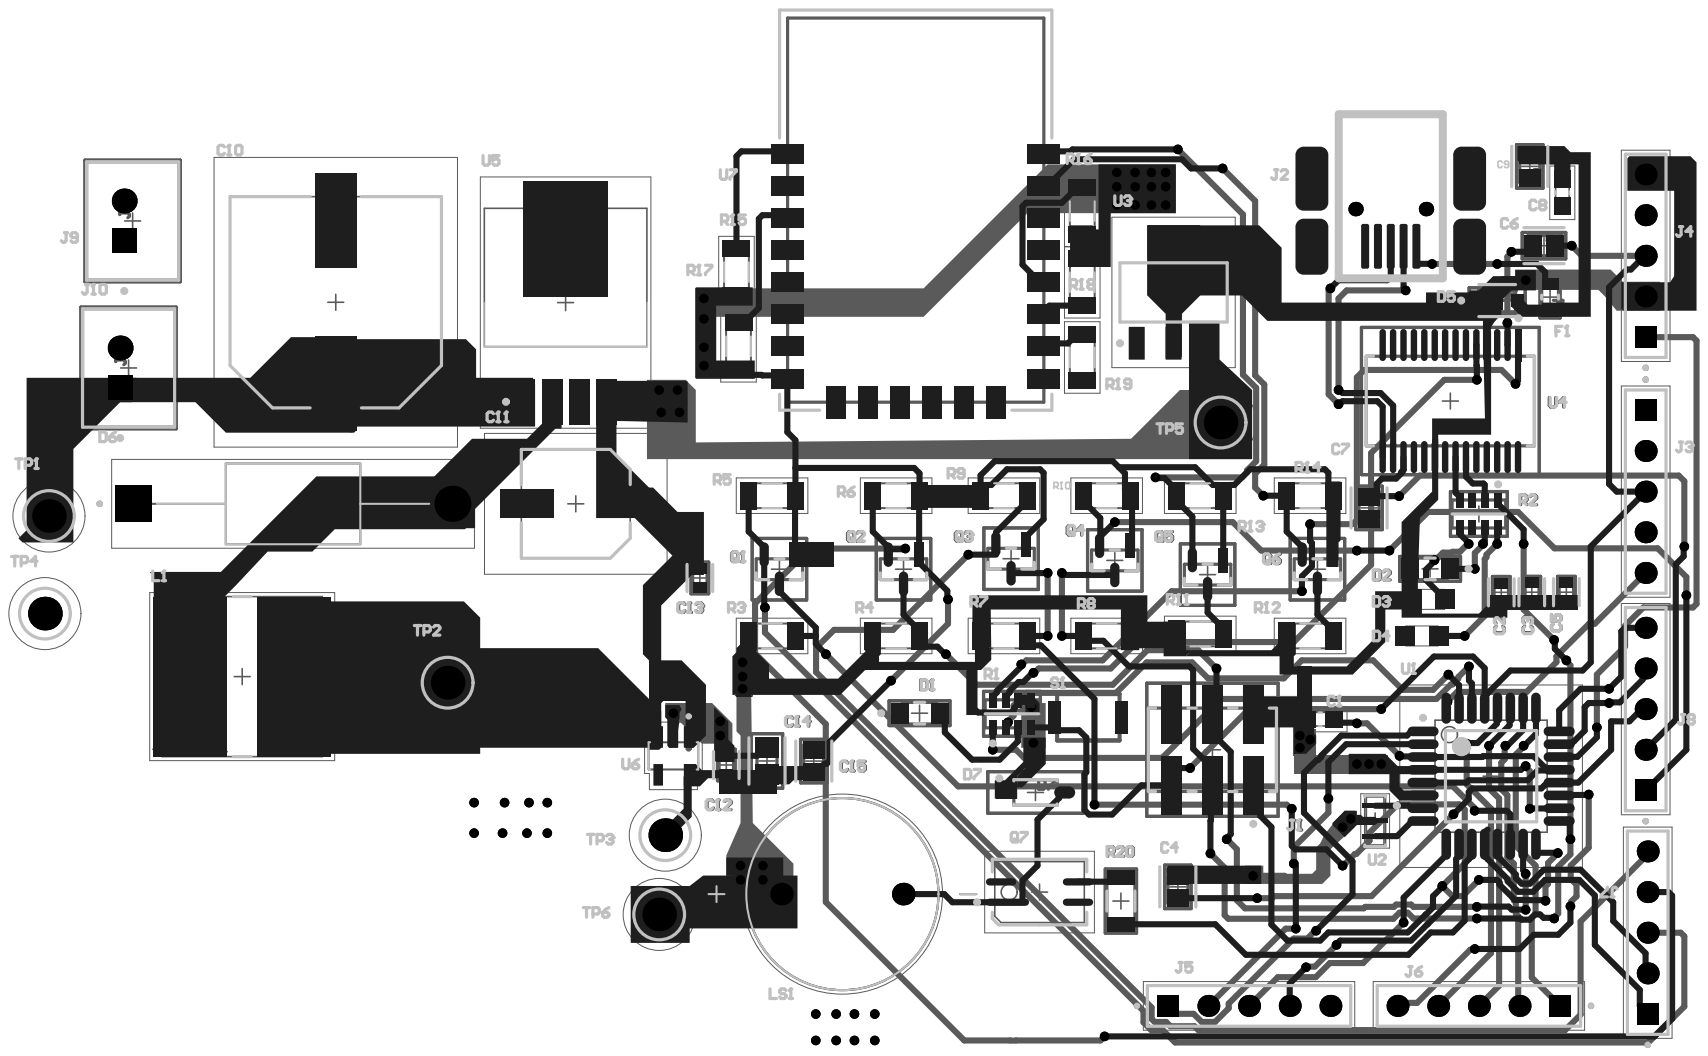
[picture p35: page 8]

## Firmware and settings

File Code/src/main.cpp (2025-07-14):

#include <Arduino.h>
#include <Pins.h>
#include <Timer.h>
#include <SerialInterface.h>
#include <SPI.h>
#include <PN532.h>

// Pin HW_MOSI(B, 2);
// Pin HW_MISO(B, 3);
// Pin HW_SCK(B, 1);
Pin NSS(B, 0);

PN532 pn532(NSS);

void setup() {
  Serial.begin(9600);
  blocking_delay(1000, MILLISECONDS);
  Serial.println("HI");

  pn532.initialize();
  blocking_delay(100, MILLISECONDS);

  pn532.SAMConfig();

  initialize_timer();
}

void loop() {
  MIFARE_Classic_PN532* card;
  card = pn532.get_mifare_classic_card();
  if (card) {
    Serial.println("FOUND");
    unsigned char key[6] = {0xff, 0xff, 0xff, 0xff, 0xff, 0xff};
    bool ok = card->authenticate_block(AUTHENTICATE_KEY_A, 0x02, key);
    if (ok) {
      Serial.println("AUTHED");
      
      unsigned char contents[16];
      if (card->read_block(0x02, contents)) {
        Serial.println("READ");
        for (int i = 0; i < 16; i++) {
          Serial.print(contents[i], HEX);
          Serial.print(", ");
        }
        Serial.println();
      } else {
        Serial.println("CUDNT READ");
      }

      blocking_delay(2000, MILLISECONDS);

      Serial.println("GONNA WRITE");
      
      unsigned char newcont[16] = {5, 1, 2, 3, 4, 5, 5, 5, 5, 5, 5, 5, 5, 5, 5, 5};
      
      if (card->write_block(0x02, newcont)) {
        Serial.println("WROTE");
      } else {
        Serial.println("CUDNT WRITE");
      }

      blocking_delay(1000, MILLISECONDS);

    } else {
      Serial.println("CUDNT AUTH");
    }
  } else {
    Serial.println("NO");
  }
  blocking_delay(500, MILLISECONDS);
}

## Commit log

2025-06-29 added Pins. kinda ugly, so many case statements, can improve? spi library works
2025-06-30 in case i accidentally delete something
2025-07-01 wrote new library for pn532. gonna commit here and erase all the pn5180 stuff in main, revert back here if 5180 needed again.
    [main.cpp]
2025-07-02 changed to testing on mega. i hardcoded spi library to lsb first, make it programmable. otherwise the code is working, i can talk to the pn532
2025-07-07 serial comm works. make bit banged implementation too ig of both spi and serial
2025-07-08 working on our pn532. made spi data order programmable
2025-07-09 completely eliminated arduino. but still using avr libraries. added buzzer. code working with our mcu+our rfid
    [main.cpp]
2025-07-14 removed avr/delay. now delaying using timers
2025-07-14 kinda make timer.h nicer
2025-07-21 added schematic files
    [Antenna.SchDoc, Overview.SchDoc, Reader.SchDoc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]
2025-07-21 added the libraries for schematics and PCB layout
    [PN532_final.PcbLib, PN532_final.SchLib]
2025-07-21 added the PCB layout
    [PN532_final.PcbDoc]
2025-07-21 added the project file for the PN532
    [PN532_final.PrjPcb]
2025-07-21 added the excel file with used components and specs
    [pn532_LCSC_components.xlsx]
